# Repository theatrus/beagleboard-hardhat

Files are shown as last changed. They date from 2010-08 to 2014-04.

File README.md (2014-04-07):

BeagleBoard Hardhat
===================

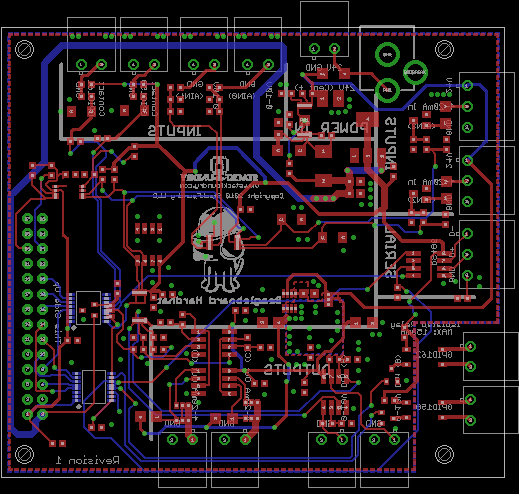
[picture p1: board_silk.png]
board silk


An original design for the
[original BeagleBoard](http://beagleboard.org/Products/BeagleBoard),
originally designed in 2010, but sadly never sold as the project which
required this set of industrial I/O did not pan out.

# Features

 * 24VDC power input, which also supplies the BeagleBoard
 * Two independent 4-20mA transmitters
 * Two 4-20mA inputs
 * Two 0-10V inputs
 * Two 0-10V outputs
 * Two small isolated relay outputs
 * A UART hook up to a half-duplex RS485 transceiver.

The analog circuits were enabled via a set of I2C ADCs and DACs
(12-bit). All other controls were via GPIO control from the
BeagleBoard - there is no on-board MCU.

# License

The CERN OHL License 1.2 is used. Please see the accompanying
LICENSE.txt file.

# Design Status

Boards were made for this design, and 2 prototypes were made from the
BOM and boards. While validation was performed, it can not be
considered bug-free.

## Boards available

A limited number of boards are available. Send an e-mail to
yann@stackfoundry.com with your mailing address. US postage is free,
International will be dealt with as it happens :-)

These boards are PCB only - no components are mounted.

# Files available

The original design is available as Eagle 6.x (XML-based) design
files, in the eagle/ directory.

Gerber files from the Eagle board file are made available in the
gerber/ directory.

Schematic PDF is available in the root of this repository.

A netlist file is available in the gerber/ directory.

# Adapting this design

All I/O to the BeagleBoard is level-shifted from 1.8V to 3.3V. If this
design is used with a 3.3V I/O device, such as a RaspberryPi, the bus
transceivers can be omitted to simply the design.

## 4-20mA transmitter

The current follower in the op-amp is a simple design, but worked well
enough in practice. The design can be modified to add more protection
against faults. The component and op-amp selection was designed to
provide tight tolerances and high performance.

## Board notes

The board is large SMT technology, and uses some fine pitch
components.

The board is "upside-down", that is the "top" faces the BeagleBoard
and the "bottom" faces the user.

## BOM Notes

A number of ceramic (MLCC) Panasonic capacitors are specified - Panasonic
exited the MLCC business, so substitutes should be found from other
suppliers (such as Samsung)

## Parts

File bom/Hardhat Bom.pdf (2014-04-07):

## Hardhat Bom

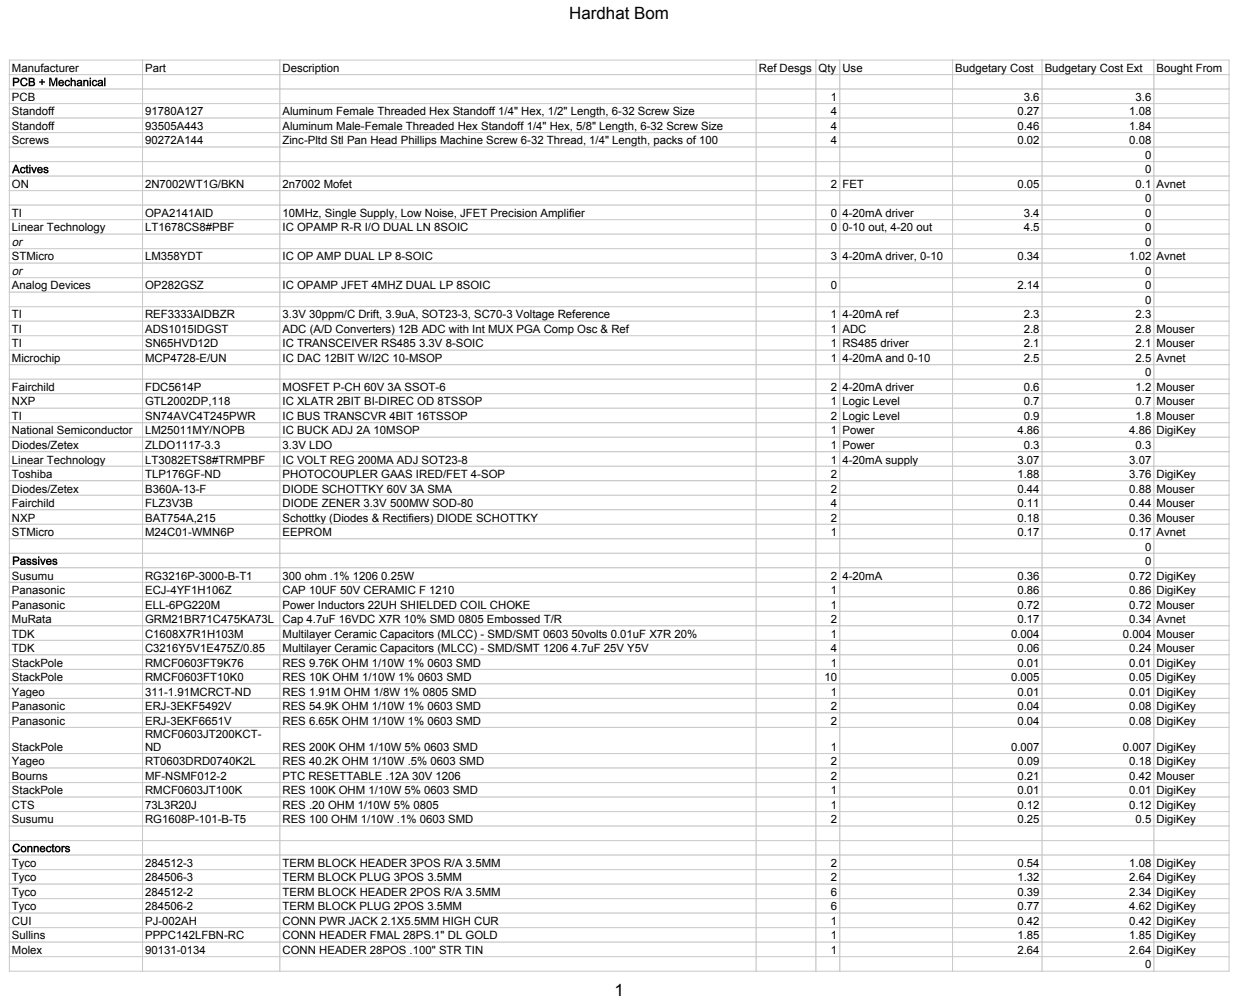
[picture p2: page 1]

Manufacturer | Part | Description | Ref Desgs | Qty | Use | Budgetary Cost | Budgetary Cost Ext | Bought From
PCB + Mechanical
PCB | | | | 1 | | 3.6 | 3.6
Standoff | 91780A127 | Aluminum Female Threaded Hex Standoff 1/4" Hex, 1/2" Length, 6-32 Screw Size | | 4 | | 0.27 | 1.08
Standoff | 93505A443 | Aluminum Male-Female Threaded Hex Standoff 1/4" Hex, 5/8" Length, 6-32 Screw Size | | 4 | | 0.46 | 1.84
Screws | 90272A144 | Zinc-Pltd Stl Pan Head Phillips Machine Screw 6-32 Thread, 1/4" Length, packs of 100 | | 4 | | 0.02 | 0.08

Actives | | | | | | | 0
ON | 2N7002WT1G/BKN | 2n7002 Mofet | | 2 | FET | 0.05 | 0.1 | Avnet

TI | OPA2141AID | 10MHz, Single Supply, Low Noise, JFET Precision Amplifier | | 0 | 4-20mA driver | 3.4 | 0
Linear Technology | LT1678CS8#PBF | IC OPAMP R-R I/O DUAL LN 8SOIC | | 0 | 0-10 out, 4-20 out | 4.5 | 0
or | | | | | | | 0
STMicro | LM358YDT | IC OP AMP DUAL LP 8-SOIC | | 3 | 4-20mA driver, 0-10 | 0.34 | 1.02 | Avnet
Analog Devices | OP282GSZ | IC OPAMP JFET 4MHZ DUAL LP 8SOIC | | 0 | | 2.14 | 0

TI | REF3333AIDBZR | 3.3V 30ppm/C Drift, 3.9uA, SOT23-3, SC70-3 Voltage Reference | | 1 | 4-20mA ref | 2.3 | 2.3
TI | ADS1015IDGST | ADC (A/D Converters) 12B ADC with Int MUX PGA Comp Osc & Ref | | 1 | ADC | 2.8 | 2.8 | Mouser
TI | SN65HVD12D | IC TRANSCEIVER RS485 3.3V 8-SOIC | | 1 | RS485 driver | 2.1 | 2.1 | Mouser
Microchip | MCP4728-E/UN | IC DAC 12BIT W/I2C 10-MSOP | | 1 | 4-20mA and 0-10 | 2.5 | 2.5 | Avnet

Fairchild | FDC5614P | MOSFET P-CH 60V 3A SSOT-6 | | 2 | 4-20mA driver | 0.6 | 1.2 | Mouser
NXP | GTL2002DP,118 | IC XLATR 2BIT BI-DIREC OD 8TSSOP | | 1 | Logic Level | 0.7 | 0.7 | Mouser
TI | SN74AVC4T245PWR | IC BUS TRANSCVR 4BIT 16TSSOP | | 2 | Logic Level | 0.9 | 1.8 | Mouser
National Semiconductor | LM25011MY/NOPB | IC BUCK ADJ 2A 10MSOP | | 1 | Power | 4.86 | 4.86 | DigiKey
Diodes/Zetex | ZLDO1117-3.3 | 3.3V LDO | | 1 | Power | 0.3 | 0.3
Linear Technology | LT3082ETS8#TRMPBF | IC VOLT REG 200MA ADJ SOT23-8 | | 1 | 4-20mA supply | 3.07 | 3.07
Toshiba | TLP176GF-ND | PHOTOCOUPLER GAAS IRED/FET 4-SOP | | 2 | | 1.88 | 3.76 | DigiKey
Diodes/Zetex | B360A-13-F | DIODE SCHOTTKY 60V 3A SMA | | 2 | | 0.44 | 0.88 | Mouser
Fairchild | FLZ3V3B | DIODE ZENER 3.3V 500MW SOD-80 | | 4 | | 0.11 | 0.44 | Mouser
NXP | BAT754A,215 | Schottky (Diodes & Rectifiers) DIODE SCHOTTKY | | 2 | | 0.18 | 0.36 | Mouser
STMicro | M24C01-WMN6P | EEPROM | | 1 | | 0.17 | 0.17 | Avnet

Passives | | | | | | | 0
Susumu | RG3216P-3000-B-T1 | 300 ohm .1% 1206 0.25W | | 2 | 4-20mA | 0.36 | 0.72 | DigiKey
Panasonic | ECJ-4YF1H106Z | CAP 10UF 50V CERAMIC F 1210 | | 1 | | 0.86 | 0.86 | DigiKey
Panasonic | ELL-6PG220M | Power Inductors 22UH SHIELDED COIL CHOKE | | 1 | | 0.72 | 0.72 | Mouser
MuRata | GRM21BR71C475KA73L | Cap 4.7uF 16VDC X7R 10% SMD 0805 Embossed T/R | | 2 | | 0.17 | 0.34 | Avnet
TDK | C1608X7R1H103M | Multilayer Ceramic Capacitors (MLCC) - SMD/SMT 0603 50volts 0.01uF X7R 20% | | 1 | | 0.004 | 0.004 | Mouser
TDK | C3216Y5V1E475Z/0.85 | Multilayer Ceramic Capacitors (MLCC) - SMD/SMT 1206 4.7uF 25V Y5V | | 4 | | 0.06 | 0.24 | Mouser
StackPole | RMCF0603FT9K76 | RES 9.76K OHM 1/10W 1% 0603 SMD | | 1 | | 0.01 | 0.01 | DigiKey
StackPole | RMCF0603FT10K0 | RES 10K OHM 1/10W 1% 0603 SMD | | 10 | | 0.005 | 0.05 | DigiKey
Yageo | 311-1.91MCRCT-ND | RES 1.91M OHM 1/8W 1% 0805 SMD | | 1 | | 0.01 | 0.01 | DigiKey
Panasonic | ERJ-3EKF5492V | RES 54.9K OHM 1/10W 1% 0603 SMD | | 2 | | 0.04 | 0.08 | DigiKey
Panasonic | ERJ-3EKF6651V | RES 6.65K OHM 1/10W 1% 0603 SMD | | 2 | | 0.04 | 0.08 | DigiKey
StackPole | RMCF0603JT200KCT-ND | RES 200K OHM 1/10W 5% 0603 SMD | | 1 | | 0.007 | 0.007 | DigiKey

Yageo | RT0603DRD0740K2L | RES 40.2K OHM 1/10W .5% 0603 SMD | | 2 | | 0.09 | 0.18 | DigiKey
Bourns | MF-NSMF012-2 | PTC RESETTABLE .12A 30V 1206 | | 2 | | 0.21 | 0.42 | Mouser
StackPole | RMCF0603JT100K | RES 100K OHM 1/10W 5% 0603 SMD | | 1 | | 0.01 | 0.01 | DigiKey
CTS | 73L3R20J | RES .20 OHM 1/10W 5% 0805 | | 1 | | 0.12 | 0.12 | DigiKey
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

54.901

Manufacturer | Part | Description | Ref Desgs | Qty | Use | Budgetary Cost | Budgetary Cost Ext | Bought From

## Hardhat Bom

2

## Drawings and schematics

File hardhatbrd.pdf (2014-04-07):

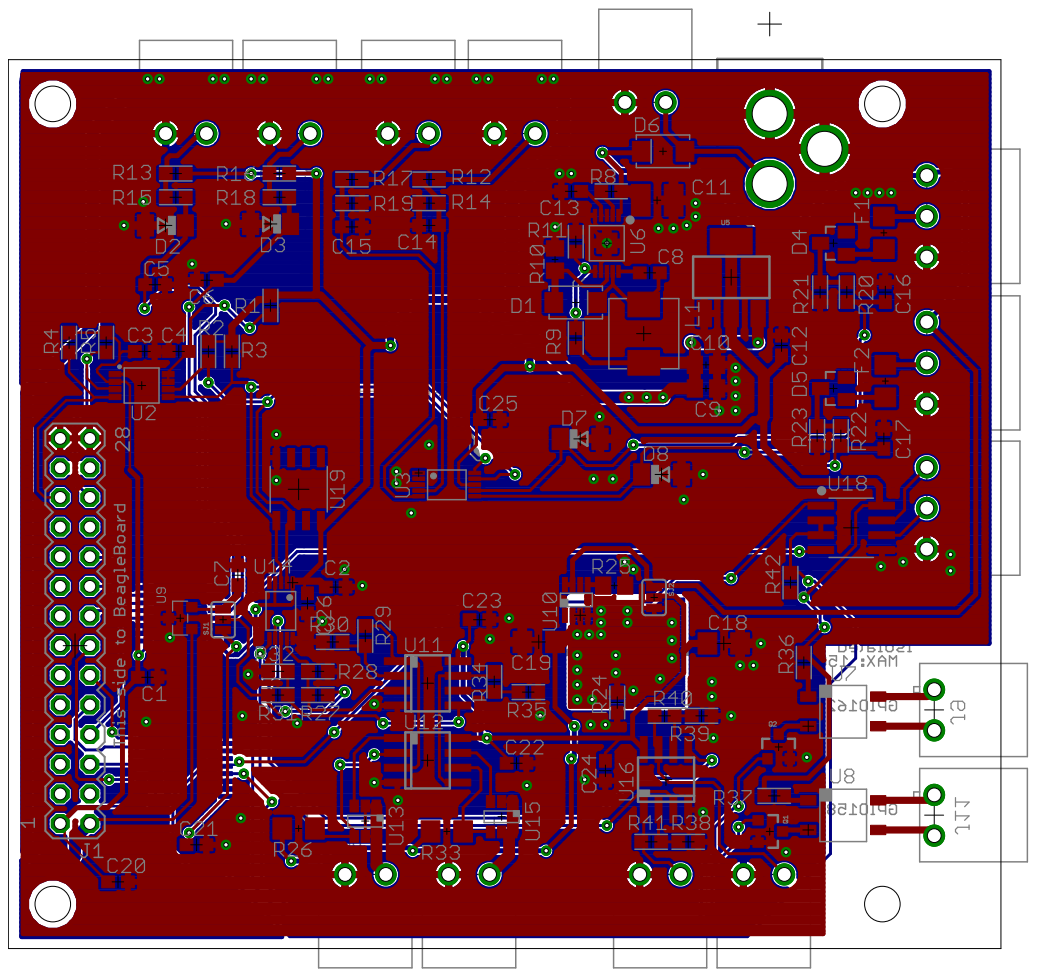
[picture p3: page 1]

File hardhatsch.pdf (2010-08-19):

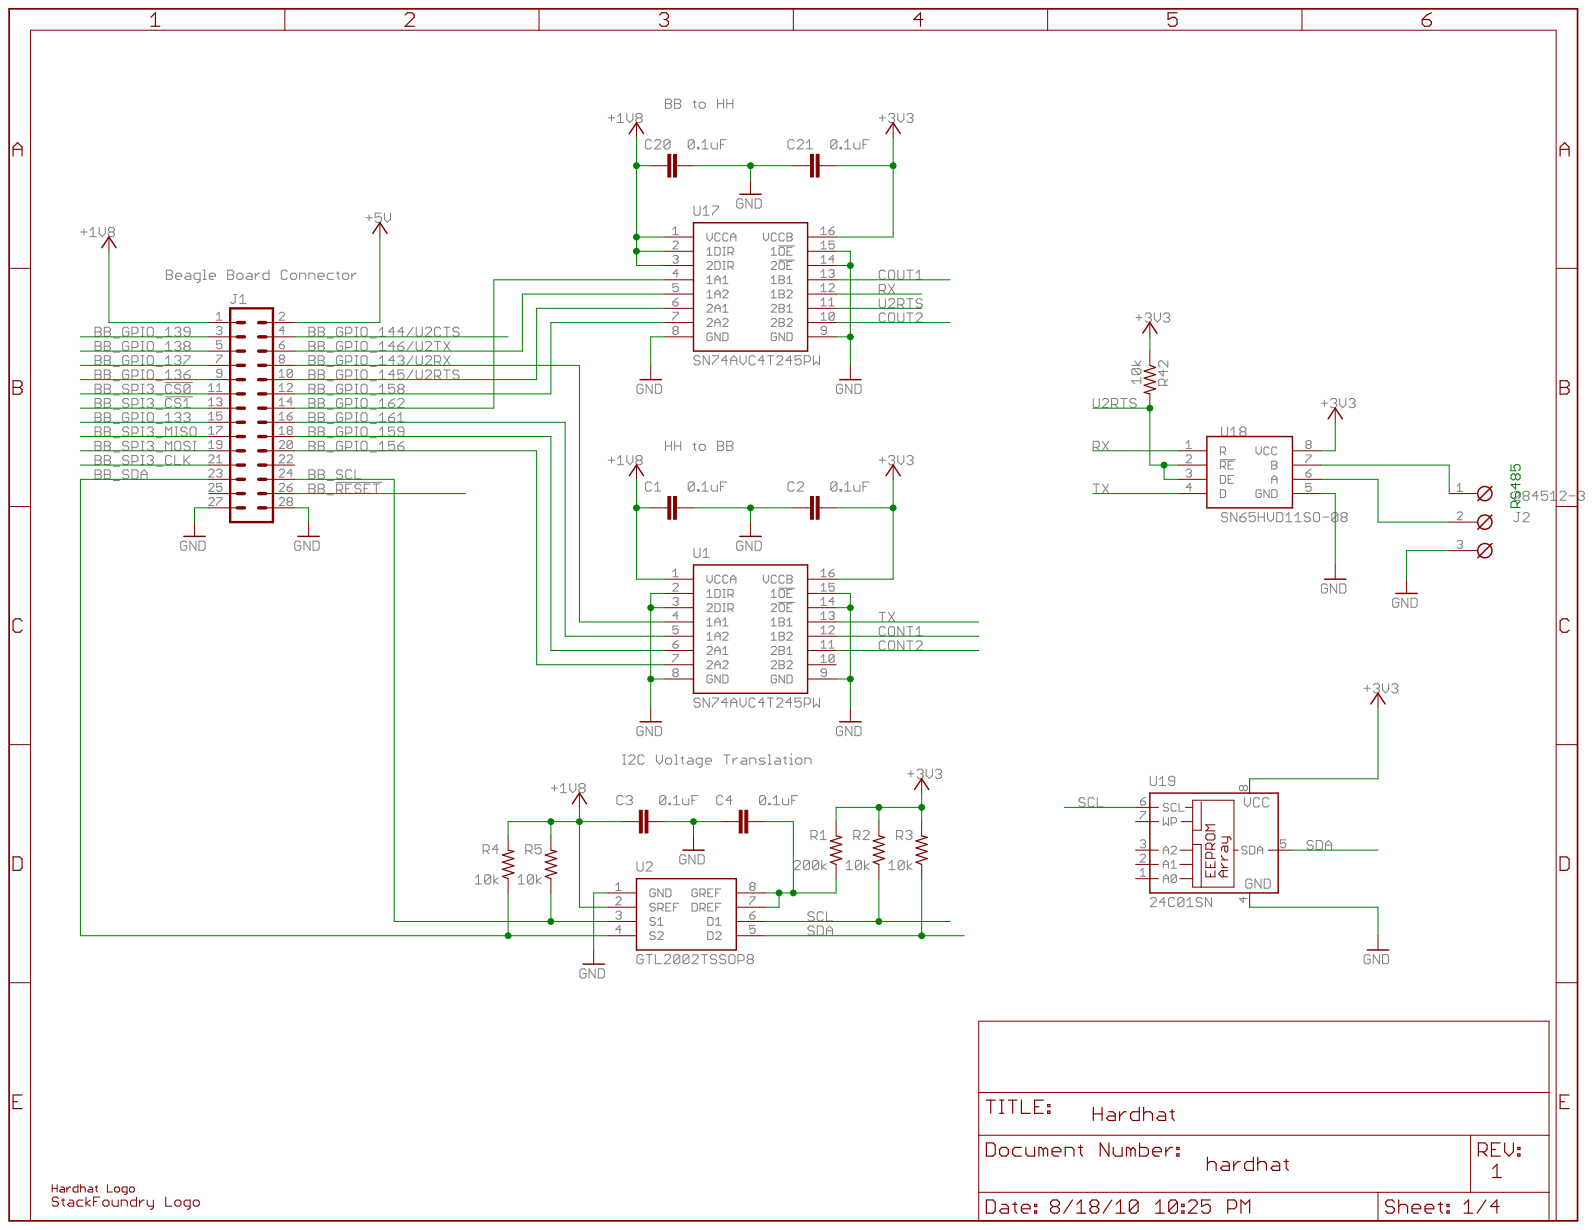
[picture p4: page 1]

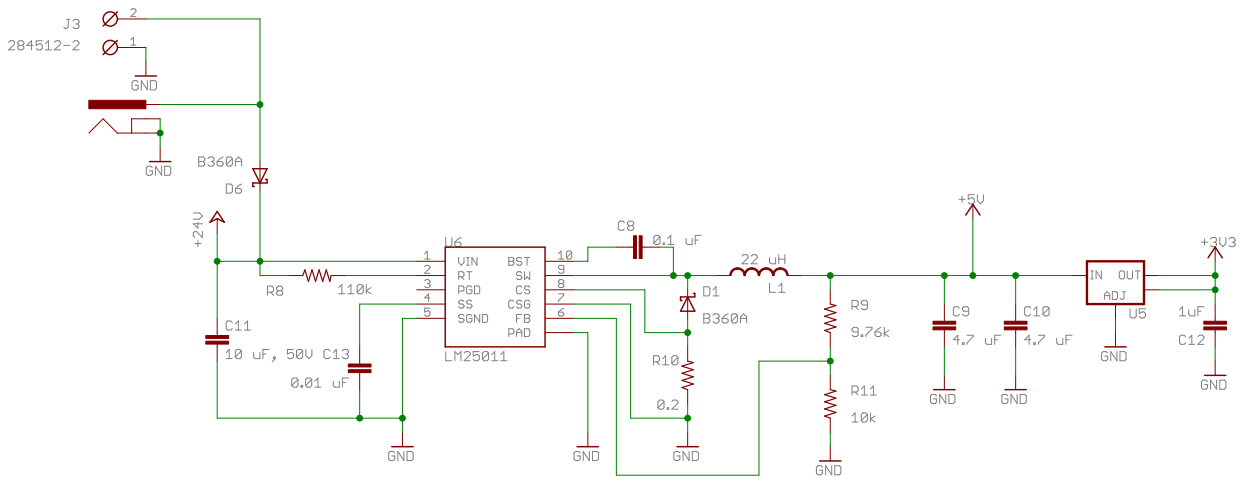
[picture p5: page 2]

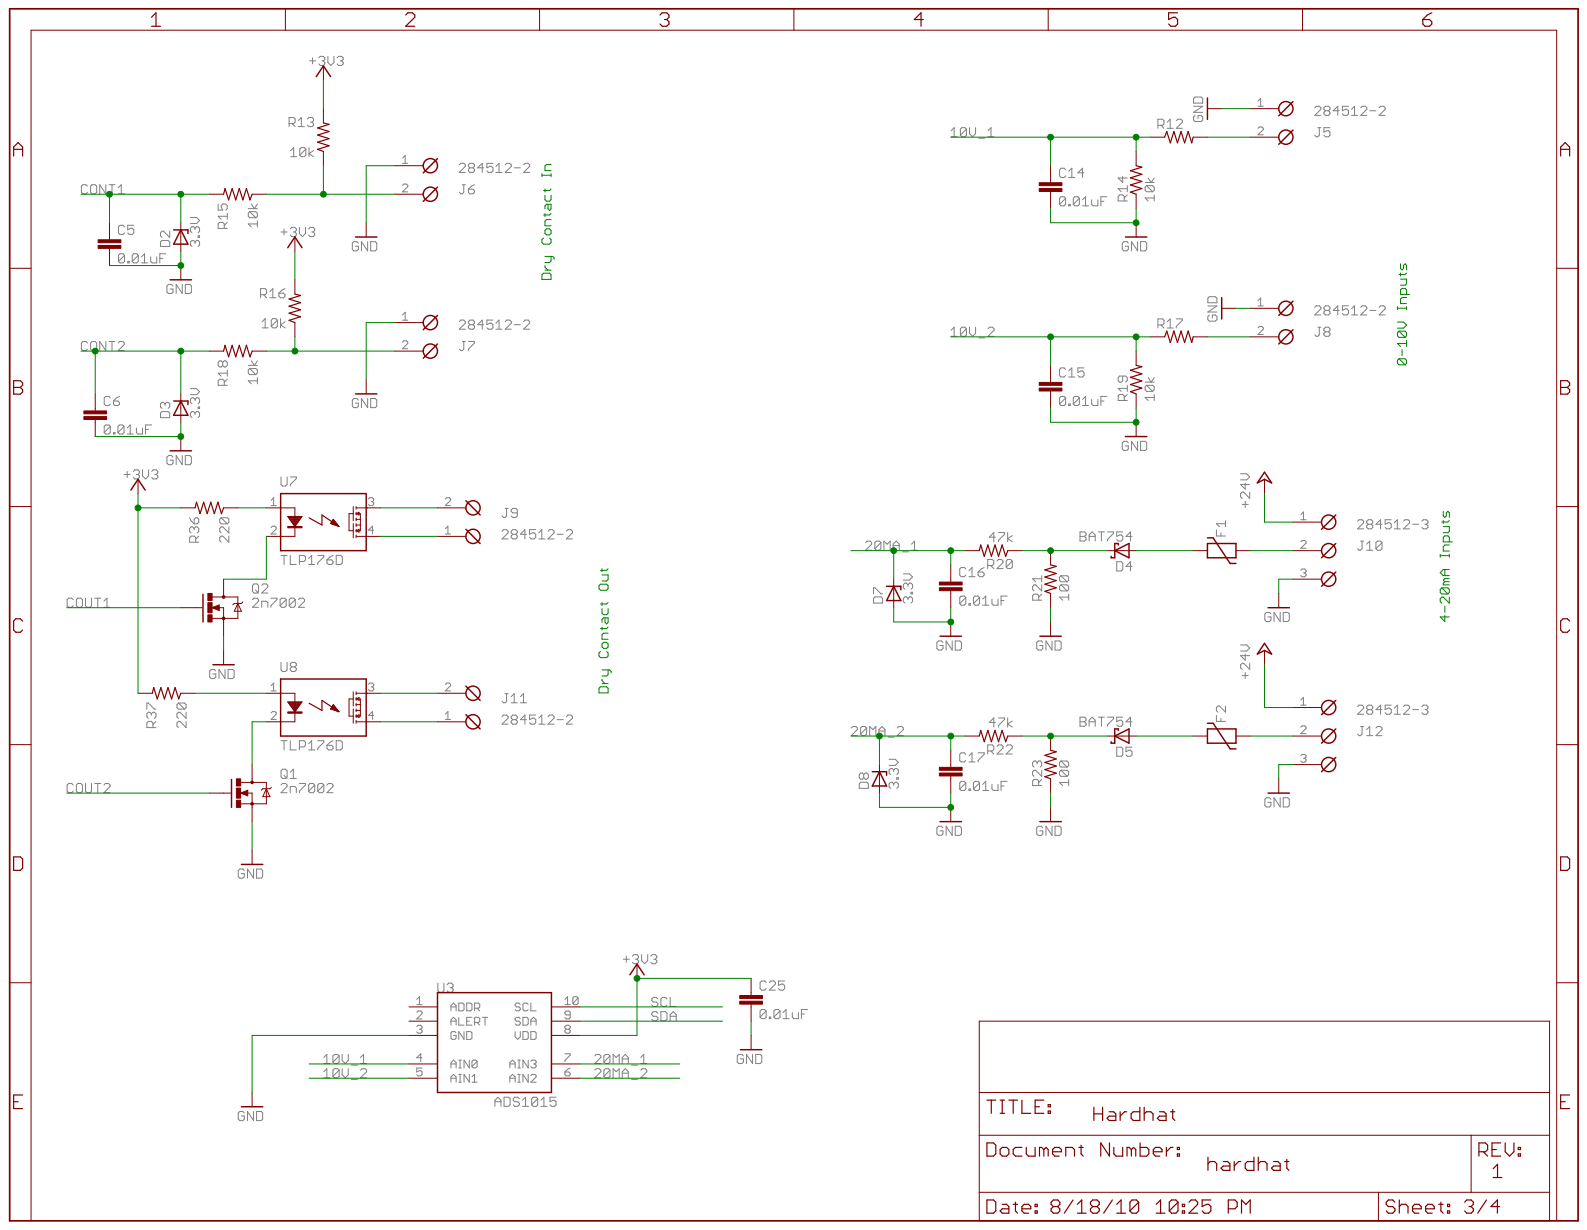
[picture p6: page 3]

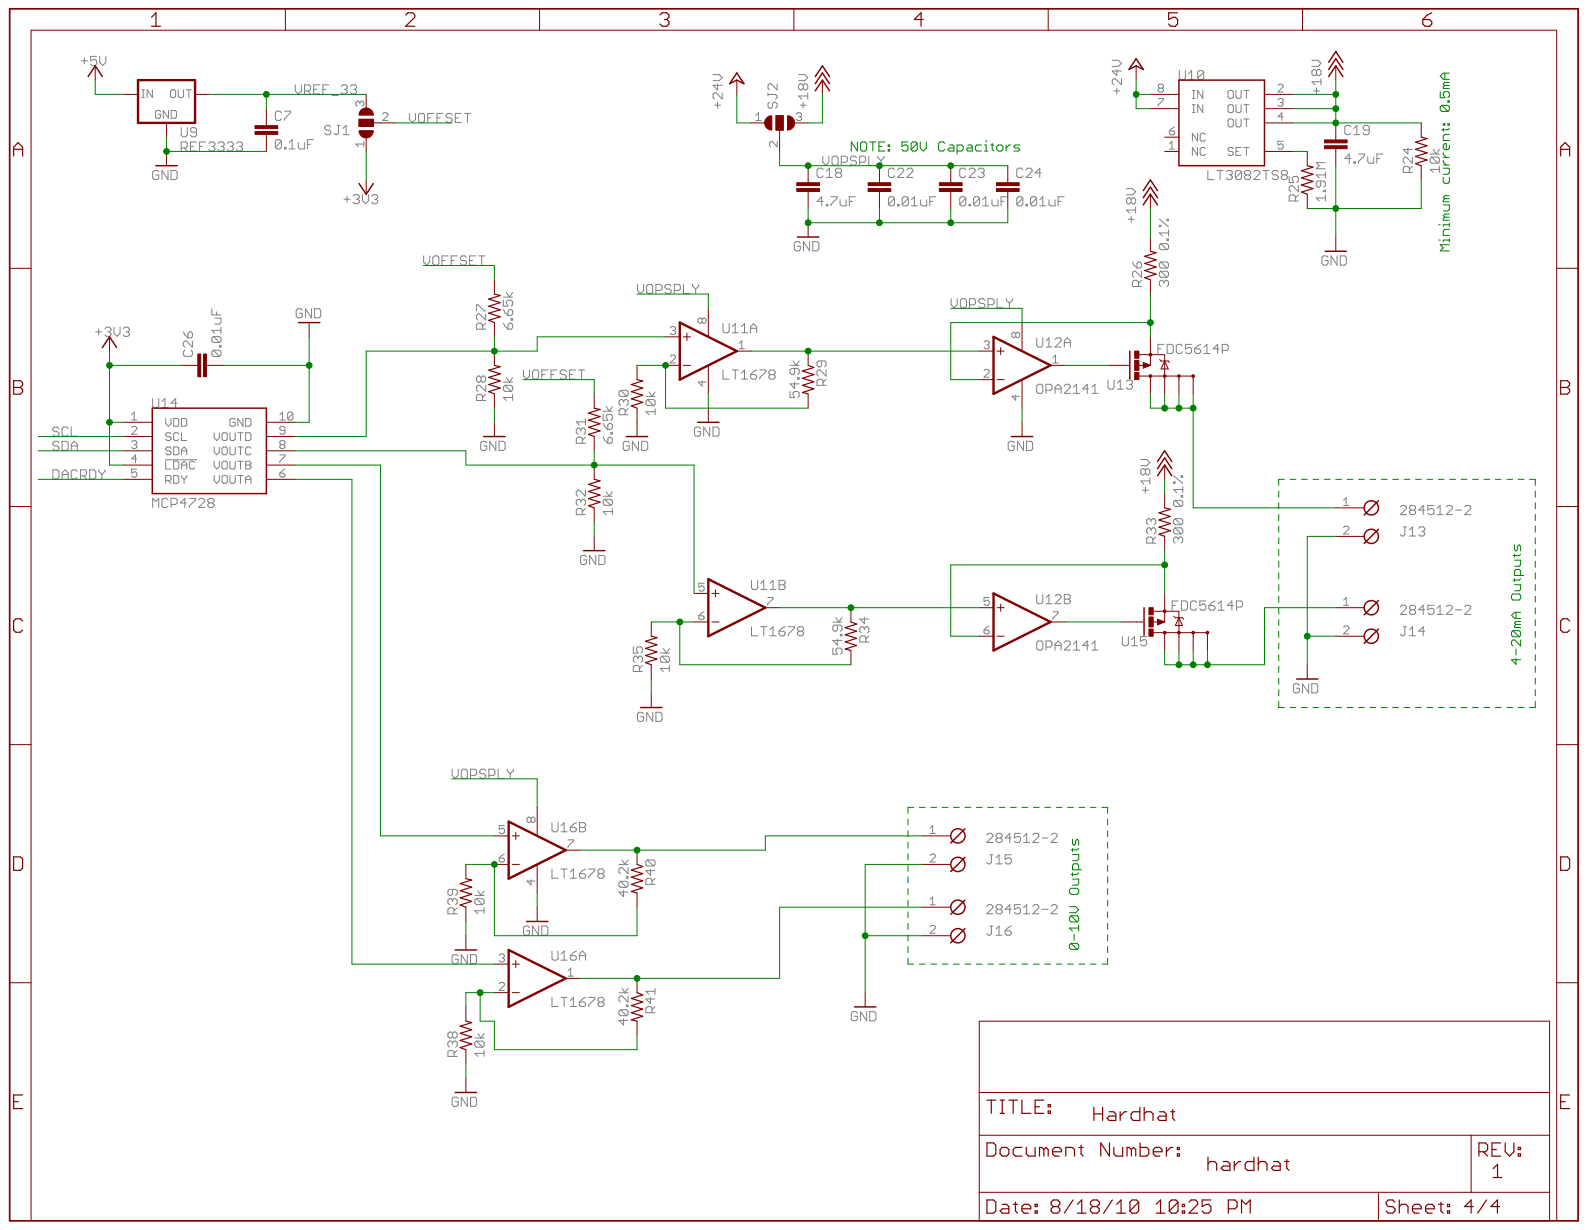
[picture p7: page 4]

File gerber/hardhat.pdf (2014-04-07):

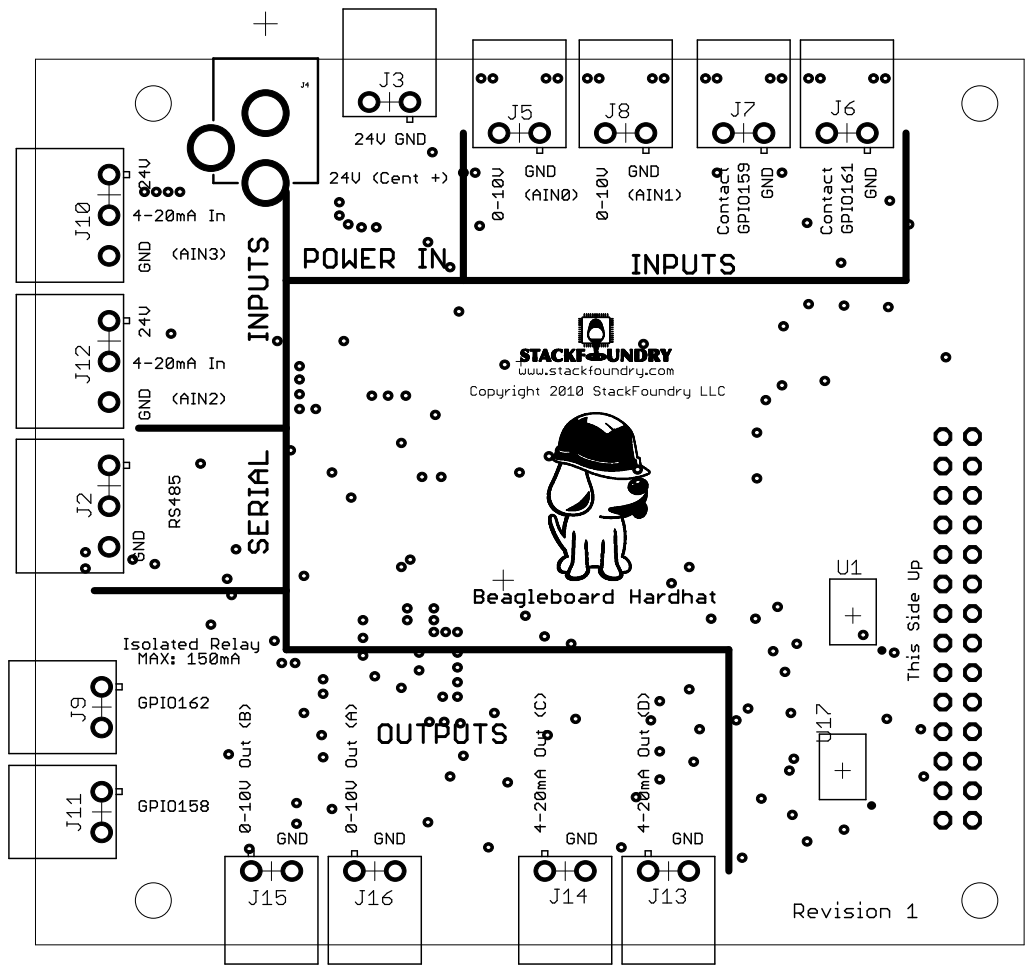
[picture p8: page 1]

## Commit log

2010-08-19 Prototype revision 1 files
    [hardhat.brd, hardhat.sch]
2010-08-19 Schematic file in PDF
2010-08-21 Update silkscreen legend
    [hardhat.brd]
2010-08-23 Update board files for latest revision, include gerber package
    [hardhat.brd, hardhat.sch]
2014-04-07 Add Gerbers and BOM
    [Hardhat Bom.csv, Hardhat Bom.ods, hardhat.brd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]
2014-04-07 Updated read me and organization
    [Hardhat Bom.csv, Hardhat Bom.ods, hardhat.brd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]
